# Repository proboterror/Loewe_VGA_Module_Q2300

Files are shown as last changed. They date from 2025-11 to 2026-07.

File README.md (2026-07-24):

# Loewe TVs Q2300 VGA Module
Recreation of VGA module PCB for Loewe TVs with Q2300 chassis.<br>
[Loewe Q2400/Q2500 Chassis VGA Module](https://github.com/proboterror/Loewe_VGA_Module_Q2500)

Project based on schematic from [Loewe Q2300 Chassis Service Manual](doc/loewe_chassis_q2300.pdf)

Schematic and PCB recreated from the scratch in KiCad and verified with Desing/Electrical Rules Checker tools.<br>

Original schematic from [Loewe Q2300 Chassis Service Manual](doc/loewe_chassis_q2300.pdf):
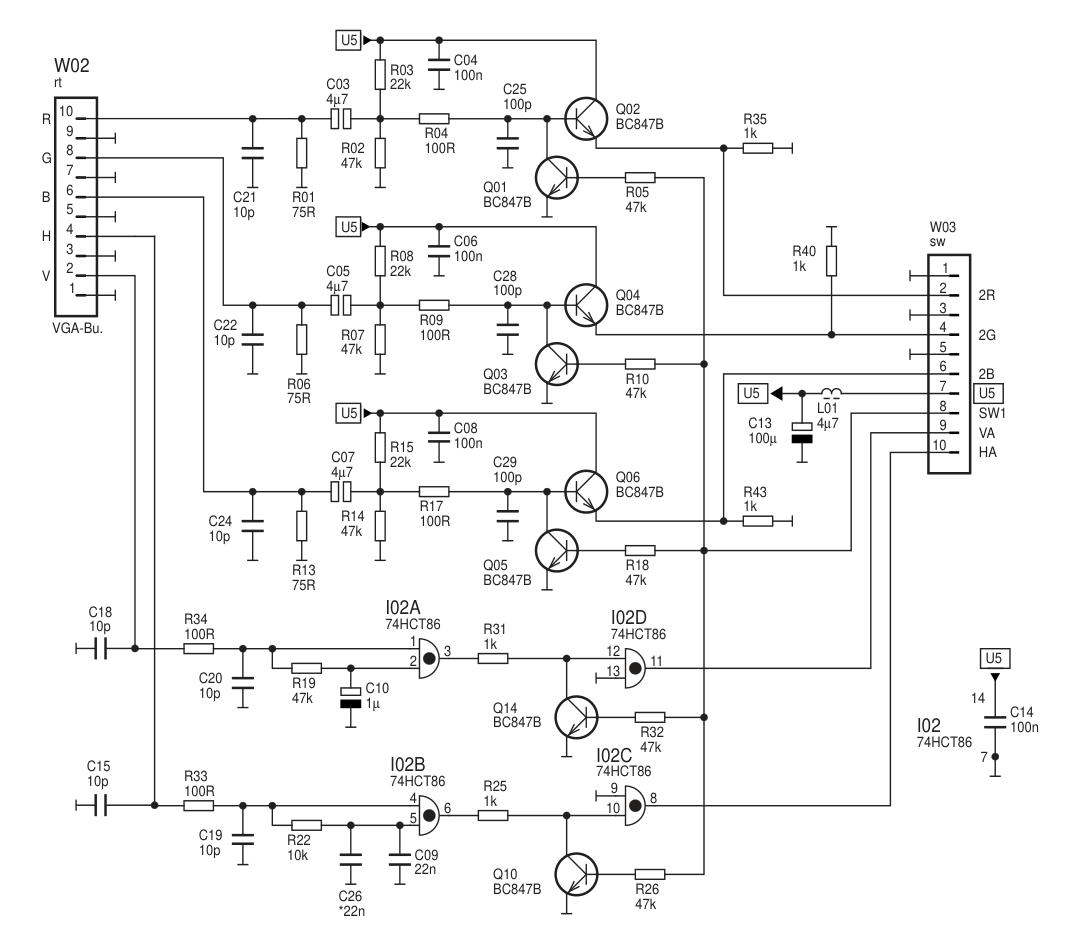
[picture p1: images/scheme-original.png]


Recreated schematic and PCB:
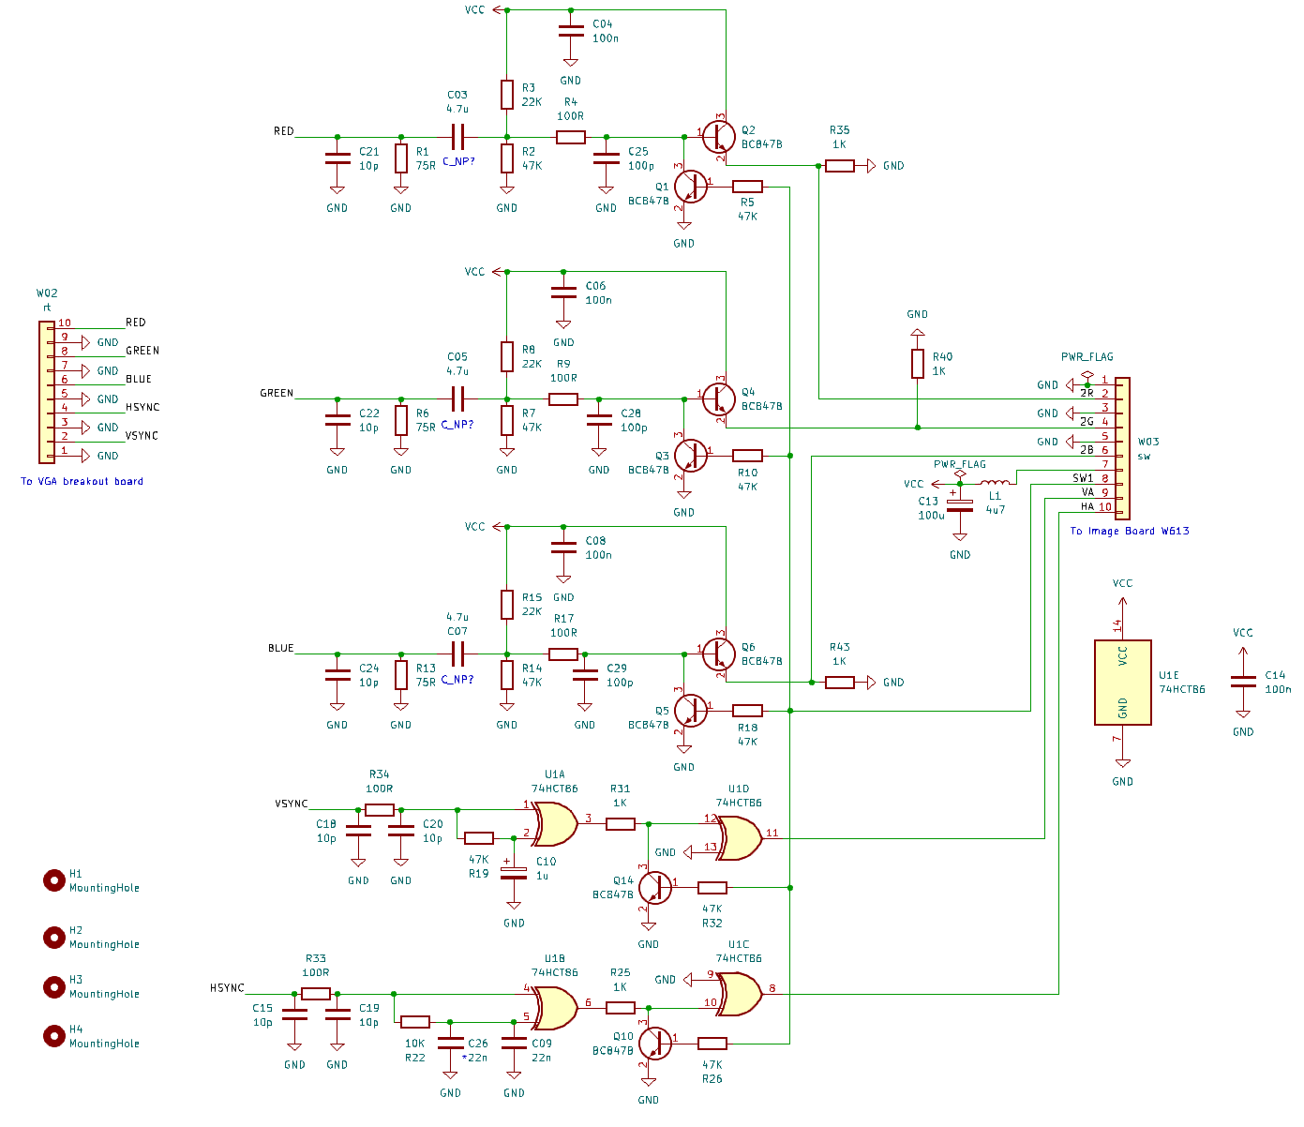
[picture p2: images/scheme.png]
scheme

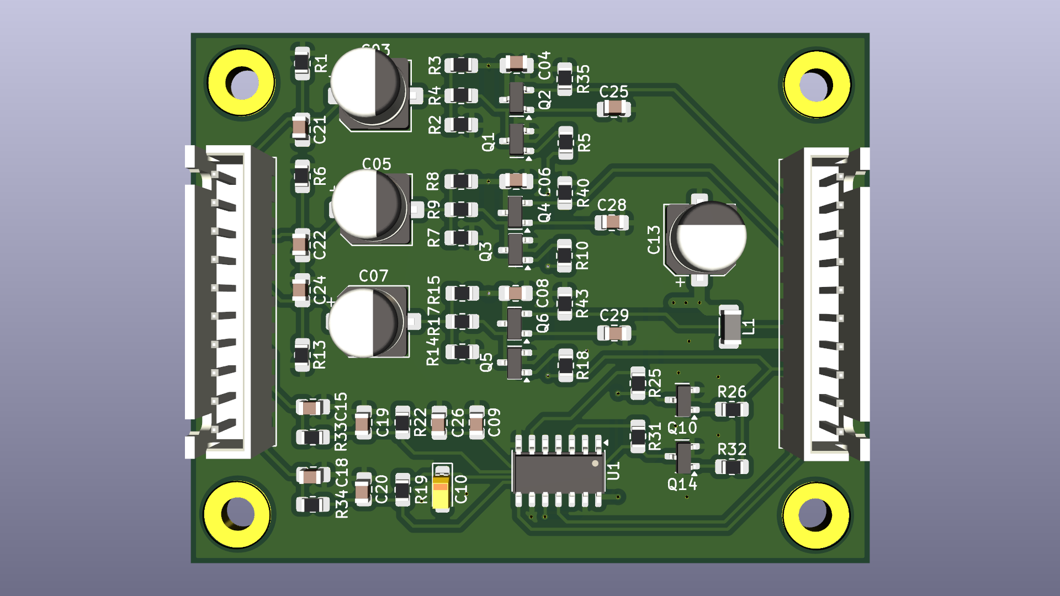
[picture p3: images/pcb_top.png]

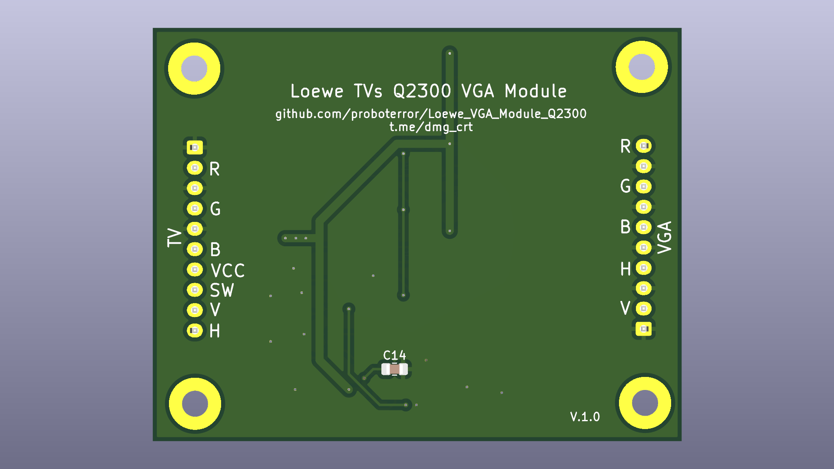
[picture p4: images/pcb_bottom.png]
pcb_bottom

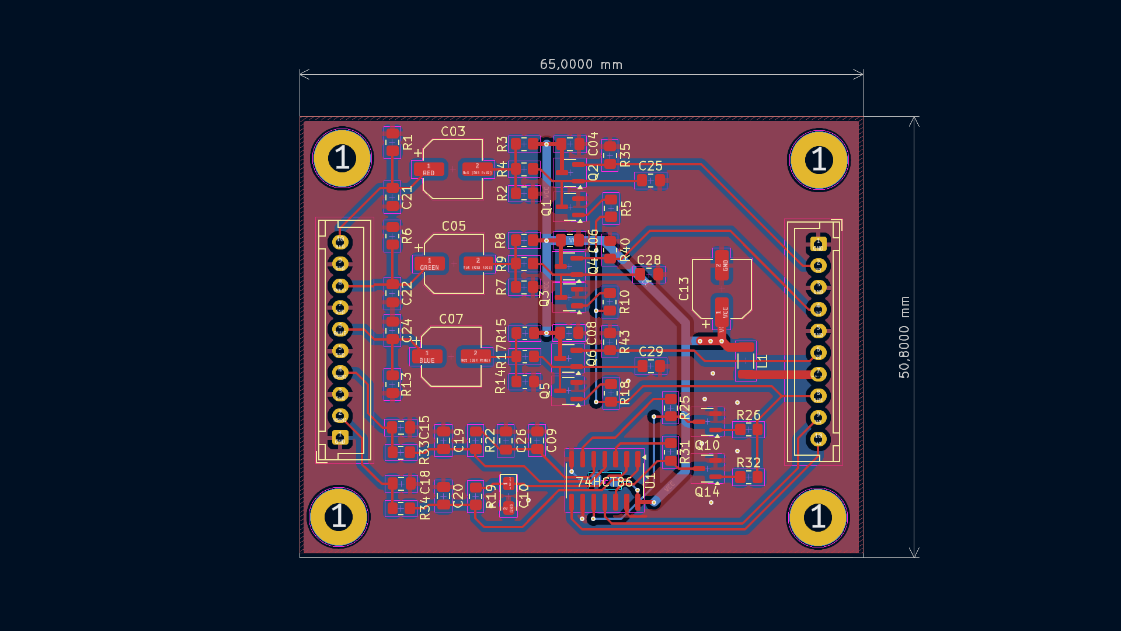
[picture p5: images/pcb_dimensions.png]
pcb_dimensions


VGA connector breakout board:
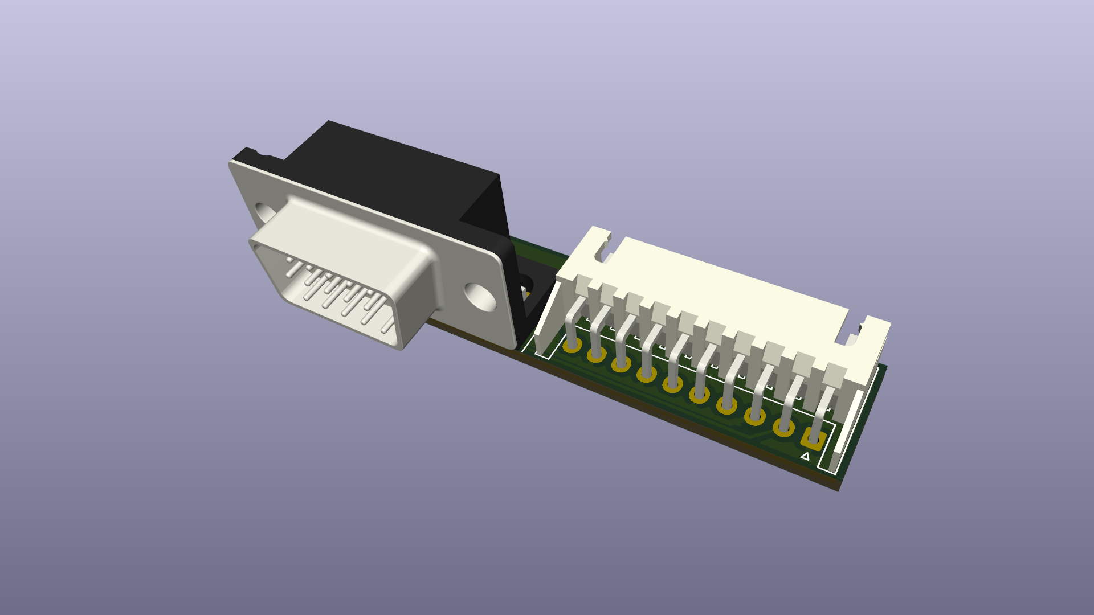
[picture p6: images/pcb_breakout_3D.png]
pcb_breakout_3D

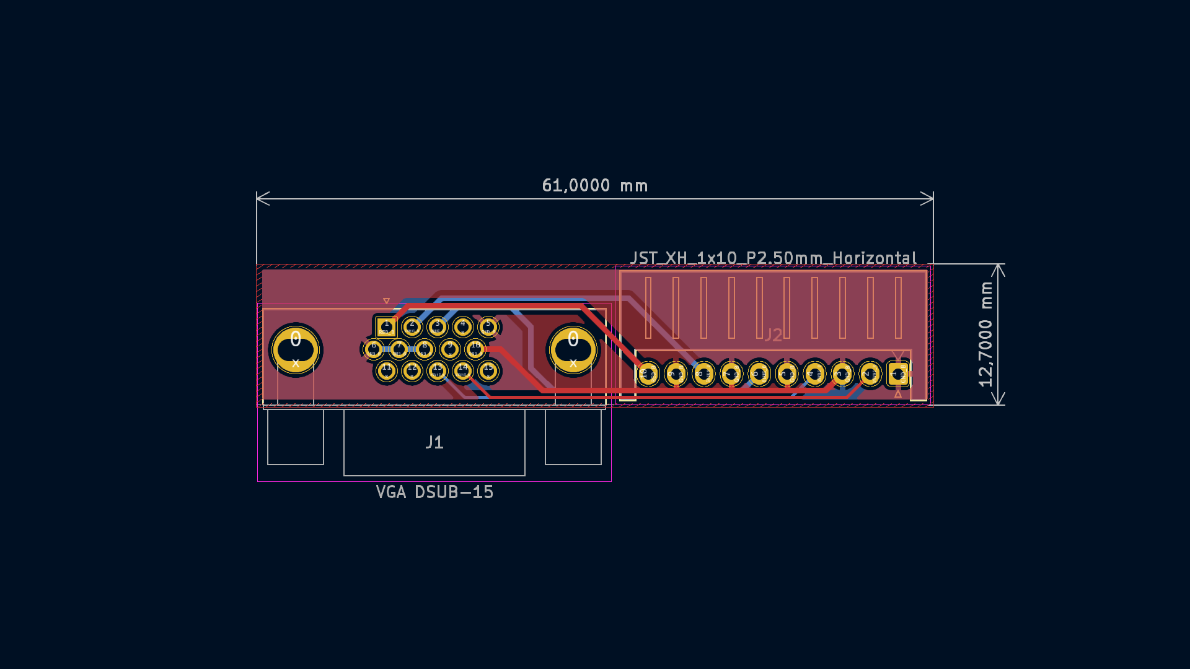
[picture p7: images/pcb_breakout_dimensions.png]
pcb_breakout_dimensions


## Bill of materials
|Reference|Value|Footprint|Qty|
|-----|-----|-----|-----|
|C3,C5,C7|4.7u|Capacitor_SMD:CP_Elec_6.3x5.4|3|
|C4,C6,C8,C14|100n|0805|4|
|C9,C26|22n|0805|2|
|C10|1u|Capacitor_Tantalum_SMD<br>CP_EIA-3216-18_Kemet-A_Pad1.58x1.35mm_HandSolder|1|
|C13|100u|Capacitor_SMD:CP_Elec_6.3x5.7|1|
|C15,C18,C19,C20,C21,C22,C24|10p|0805|7|
|C25,C28,C29|100p|0805|3|
|J1|VGA DSUB-15|DSUB-15-HD_Male_Horizontal_P2.29x1.98mm<br>EdgePinOffset3.03mm_MountingHolesOffset4.94mm|1|
|J2|JST XH 10 pin Horizontal|JST_XH_S10B-XH-A_1x10_P2.50mm_Horizontal|1|
|L1|4u7|Inductor_SMD:1206|1|
|Q1,Q2,Q3,Q4,Q5,Q6,Q10,Q14|BC847B|SOT-23|8|
|R1,R6,R13|75R|0805|3|
|R2,R5,R7,R10,R14,R18,R19,R26,R32|47K|0805|9|
|R3,R8,R15|22K|0805|3|
|R4,R9,R17,R33,R34|100R|0805|5|
|R22|10K|0805|1|
|R25,R31,R35,R40,R43|1K|0805|5|
|U1|74HCT86|SO-14_3.9x8.65mm_P1.27mm|1|
|W2|JST XH 10 pin Vertical|JST_XH_B10B-XH-A_1x10_P2.50mm_Vertical|1|
|W3|JST XH 10 pin Vertical|JST_XH_B10B-XH-A_1x10_P2.50mm_Vertical|1|

+Cables XH 10 pin 20 + 30~50 cm, connectors: same side

## Order boards from manufacturer
Project split to 2 PCBs which should be ordered separately.
Send "gerbers\Breakout Board" and "gerbers\Main Board" folders content packed to separate zip archives.

## Build Notes
L1 inductor can be replaced with 0R resistor or solder bridge.

Pay attention on cables connectors type: same direction or reverse direction.

## Install
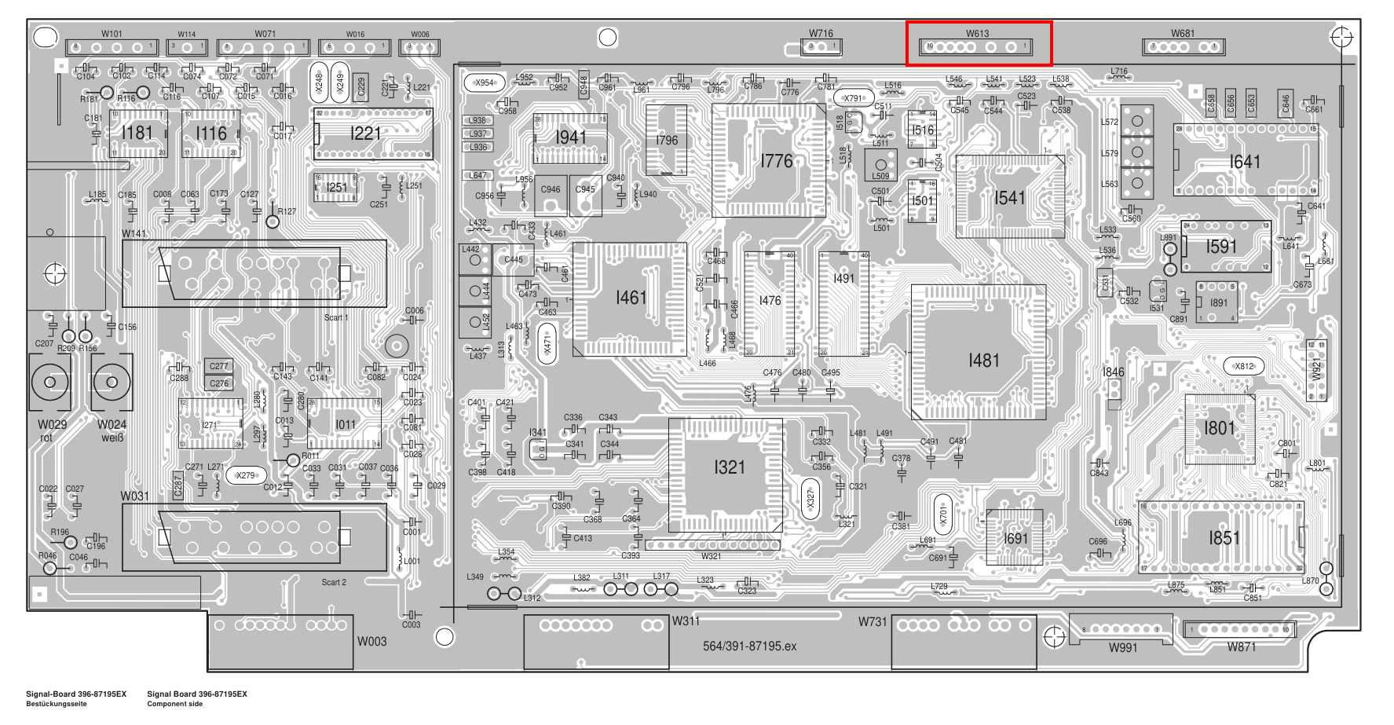
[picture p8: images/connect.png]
Module connection diagram


<https://www.youtube.com/watch?v=7eVl5yn5JIE>:<br>
Select VGA input:<br>
@djcalle1975:
> On the Q23 you have to navigate to channel 196 and if no input is detected within 10 seconds the TV will default back to the last used channel.

VGA Geometry menu:<br>
@peteagas:
> If there is no VGA menu for you on a Q23 after installation and after enabling the option byte setting, press the "i" on the Loewe remote then go to select control level then simple control level set to "No". VGA geometry will now be available to use.

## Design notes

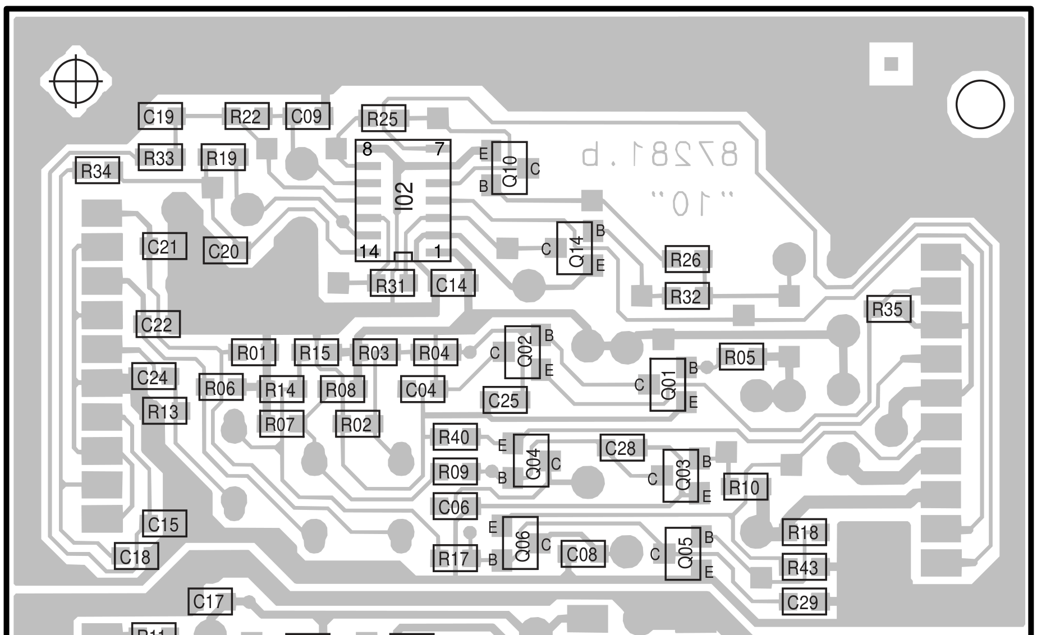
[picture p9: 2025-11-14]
images/pcb.png

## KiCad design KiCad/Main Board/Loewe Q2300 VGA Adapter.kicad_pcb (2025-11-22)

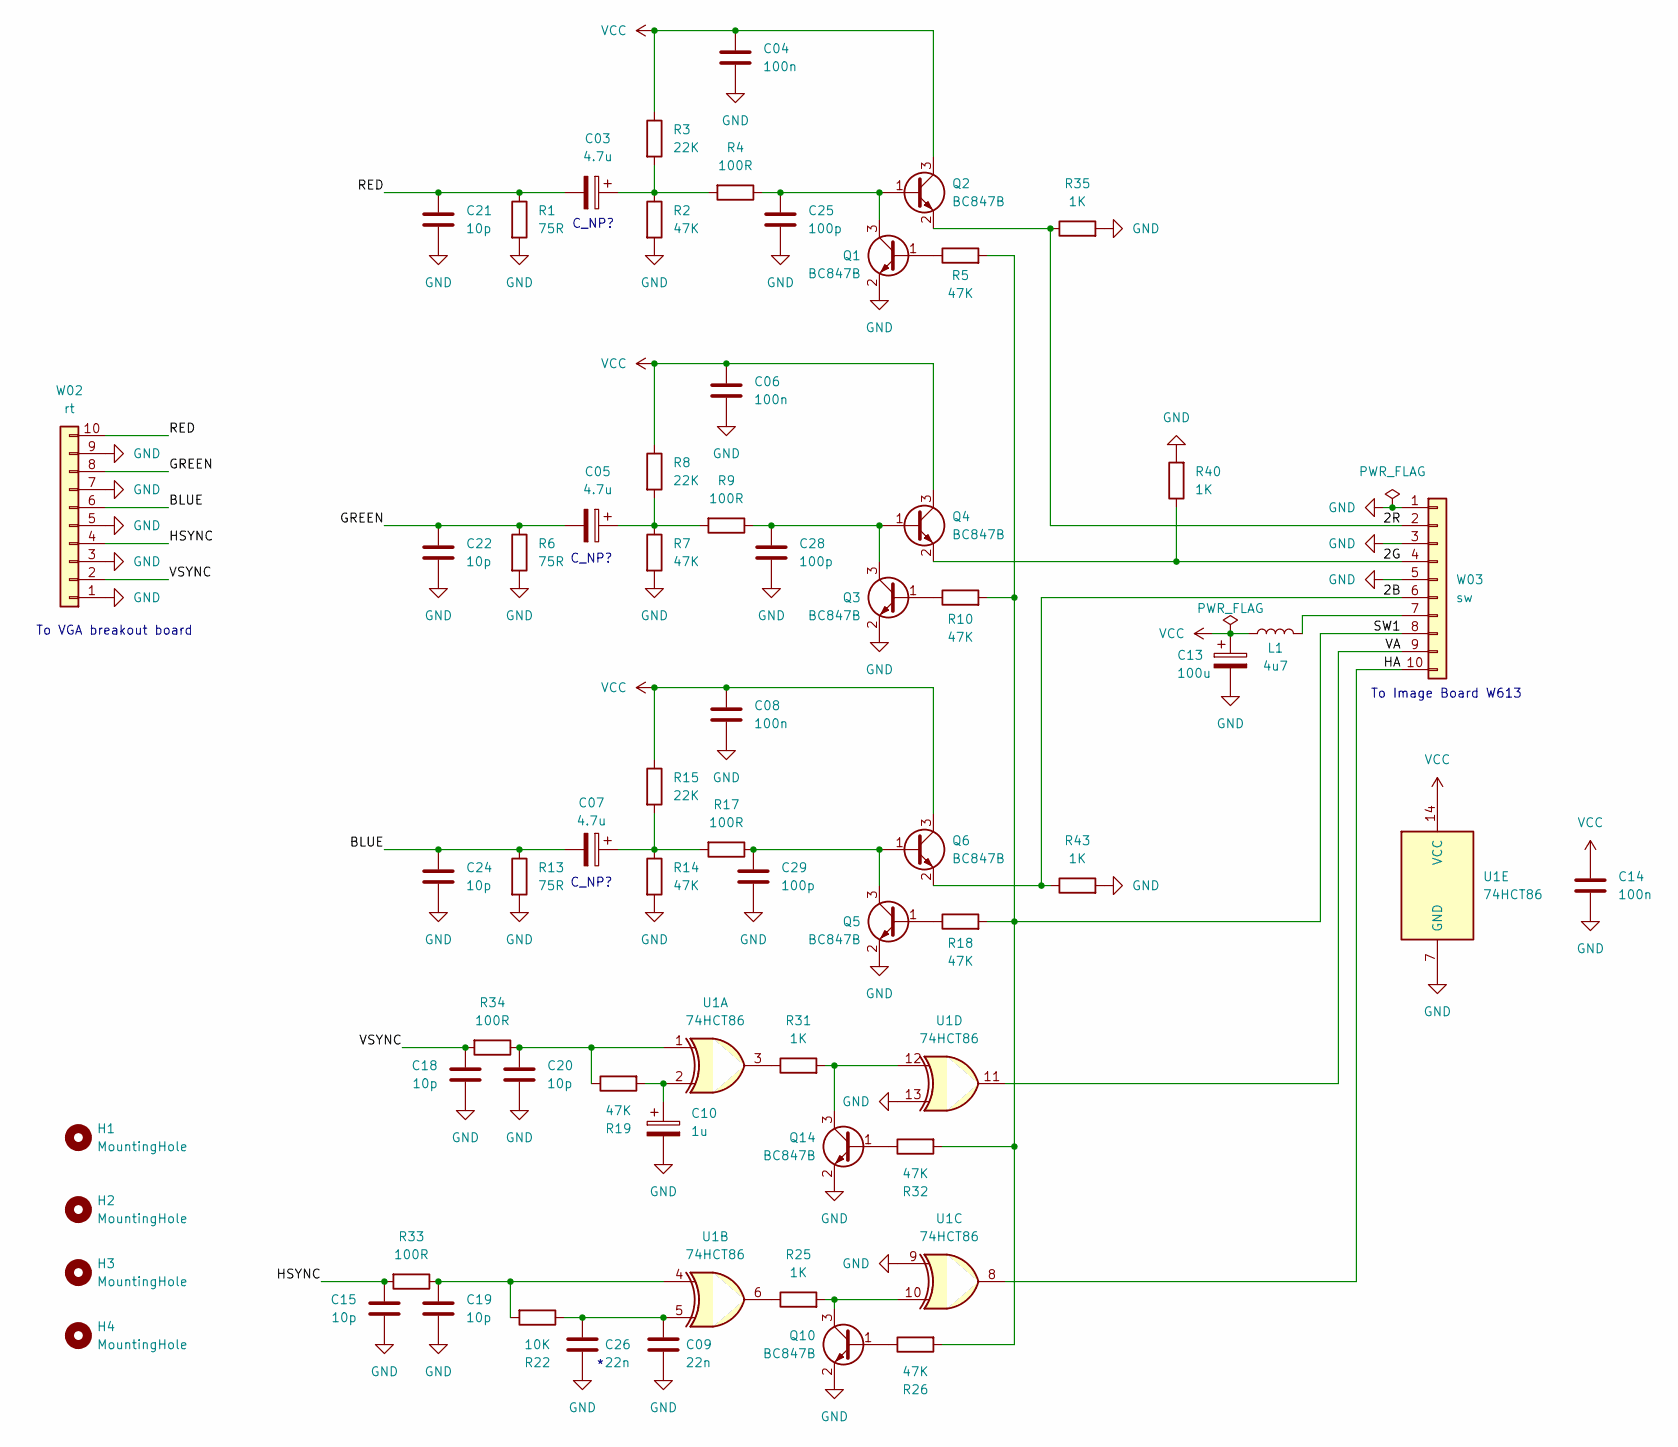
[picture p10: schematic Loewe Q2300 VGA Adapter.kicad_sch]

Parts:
C03, C05, C07: 4.7u; CP_Elec_4x5.4
C04, C06, C08, C14: 100n; C_0805_2012Metric_Pad1.18x1.45mm_HandSolder
C09, C26: 22n; C_0805_2012Metric_Pad1.18x1.45mm_HandSolder
C10: 1u; CP_EIA-3216-18_Kemet-A_Pad1.58x1.35mm_HandSolder
C13: 100u; CP_Elec_6.3x5.7
C15, C18, C19, C20, C21, C22, C24: 10p; C_0805_2012Metric_Pad1.18x1.45mm_HandSolder
C25, C28, C29: 100p; C_0805_2012Metric_Pad1.18x1.45mm_HandSolder
H1, H2, H3, H4: MountingHole; MountingHole_3.2mm_M3_Pad
L1: 4u7; L_1210_3225Metric_Pad1.42x2.65mm_HandSolder
Q1, Q2, Q3, Q4, Q5, Q6, Q10, Q14: BC847B; SOT-23
R1, R6, R13: 75R; R_0805_2012Metric_Pad1.20x1.40mm_HandSolder
R2, R5, R7, R10, R14, R18, R19, R26, R32: 47K; R_0805_2012Metric_Pad1.20x1.40mm_HandSolder
R3, R8, R15: 22K; R_0805_2012Metric_Pad1.20x1.40mm_HandSolder
R4, R9, R17, R33, R34: 100R; R_0805_2012Metric_Pad1.20x1.40mm_HandSolder
R22: 10K; R_0805_2012Metric_Pad1.20x1.40mm_HandSolder
R25, R31, R35, R40, R43: 1K; R_0805_2012Metric_Pad1.20x1.40mm_HandSolder
U1: 74HCT86; SO-14_3.9x8.65mm_P1.27mm
W02: rt; JST_XH_B10B-XH-A_1x10_P2.54mm_Vertical
W03: sw; JST_XH_B10B-XH-A_1x10_P2.54mm_Vertical

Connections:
/2B: Q6.2 (E), R43.1, W03.6
/2G: Q4.2 (E), R40.1, W03.4
/2R: Q2.2 (E), R35.1, W03.2
/BLUE: C07.2, C24.1, R13.1, W02.6
/GREEN: C05.2, C22.1, R6.1, W02.8
/HA: U1.8, W03.10
/HSYNC: C15.2, R33.2, W02.4
/RED: C03.2, C21.1, R1.1, W02.10
/SW1: R5.2, R10.2, R18.2, R26.2, R32.2, W03.8
/VA: U1.11, W03.9
/VSYNC: C18.1, R34.2, W02.2
GND: C04.2, C06.2, C08.2, C09.1, C10.2, C13.2, C14.2, C15.1, C18.2, C19.1, C20.1, C21.2, C22.2, C24.2, C25.2, C26.1, C28.2, C29.2, Q1.2 (E), Q3.2 (E), Q5.2 (E), Q10.2 (E), Q14.2 (E), R1.2, R2.2, R6.2, R7.2, R13.2, R14.2, R35.2, R40.2, R43.2, U1.7 (GND), U1.9, U1.13, W02.1, W02.3, W02.5, W02.7, W02.9, W03.1, W03.3, W03.5
unnamed: C03.1, R2.1, R3.2, R4.2
unnamed: C05.1, R7.1, R8.2, R9.2
unnamed: C07.1, R14.1, R15.2, R17.2
unnamed: C09.2, C26.2, R22.1, U1.5
unnamed: C10.1, R19.2, U1.2
unnamed: C19.2, R22.2, R33.1, U1.4
unnamed: C20.2, R19.1, R34.1, U1.1
unnamed: Q1.1 (B), R5.1
unnamed: C25.1, Q1.3 (C), Q2.1 (B), R4.1
unnamed: Q3.1 (B), R10.1
unnamed: C28.1, Q3.3 (C), Q4.1 (B), R9.1
unnamed: Q5.1 (B), R18.1
unnamed: C29.1, Q5.3 (C), Q6.1 (B), R17.1
unnamed: Q10.1 (B), R26.1
unnamed: Q10.3 (C), R25.2, U1.10
unnamed: Q14.1 (B), R32.1
unnamed: Q14.3 (C), R31.2, U1.12
unnamed: R25.1, U1.6
unnamed: R31.1, U1.3
unnamed: L1.2, W03.7
VCC: C04.1, C06.1, C08.1, C13.1, C14.1, L1.1, Q2.3 (C), Q4.3 (C), Q6.3 (C), R3.1, R8.1, R15.1, U1.14 (VCC)

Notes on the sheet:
To VGA breakout board
C_NP?
To Image Board W613

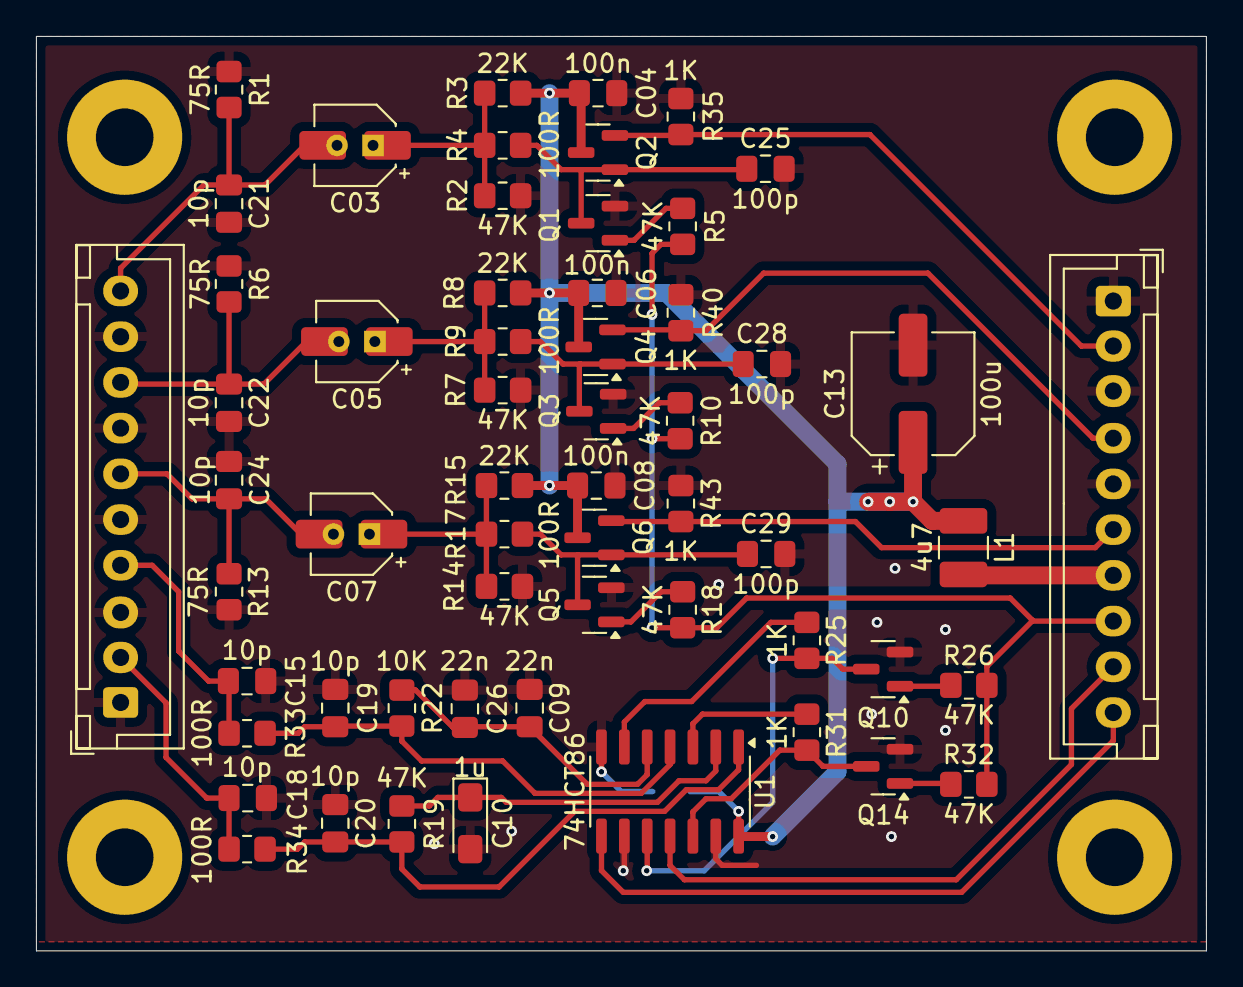
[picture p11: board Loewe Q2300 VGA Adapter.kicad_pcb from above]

Board: 2 copper layers, 65.0 x 50.8 mm, 63 parts (1 on the bottom side), 33 nets.

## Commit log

2025-11-14 Initial schematic and PCB. Project description.
    [Loewe Q2300 Breakout Board.kicad_pcb, Loewe Q2300 Breakout Board.kicad_sch, Loewe Q2300 VGA Adapter.kicad_pcb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]
2025-11-14 Change L1 inductor footprint to 1210 (TDK/EPCOS NLCV32T-4R7M-EF).
    [Loewe Q2300 VGA Adapter.kicad_pcb, Loewe Q2300 VGA Adapter.kicad_sch]
2025-11-14 Change RGB input capacitors footprints to Capacitor_SMD:CP_Elec_4x5.4. Reverse RGB capacitors polarity.
    [Loewe Q2300 VGA Adapter.kicad_pcb, Loewe Q2300 VGA Adapter.kicad_sch]
2025-11-16 Move components values from *.Fab layer to *.SilkS. Align mounting holes positions to 55/40 mm.
    [Loewe Q2300 VGA Adapter.kicad_pcb]
2025-11-22 Add non-standard 2.54 mm JST XH S10B connectors footprints based on KiCad 2.50 mm ones.
2025-11-22 Replace JST XH 2.50 mm with custom 2.54 mm.
    [Loewe Q2300 Breakout Board.kicad_pcb, Loewe Q2300 Breakout Board.kicad_sch, Loewe Q2300 VGA Adapter.kicad_pcb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]
2025-11-22 Edit PCB dimensions drawing.
    [Loewe Q2300 Breakout Board.kicad_pcb]
2025-11-22 Replace footprint for RGB input capacitors with custom combined SMD/THT one.
    [Loewe Q2300 VGA Adapter.kicad_pcb, Loewe Q2300 VGA Adapter.kicad_sch]
2025-11-22 Add version to PCB silkscreen.
    [Loewe Q2300 Breakout Board.kicad_pcb]
2025-11-22 Production V.1.0 gerbers.
    [Loewe Q2300 Breakout Board-B_Cu.gbr, Loewe Q2300 Breakout Board-B_Mask.gbr, Loewe Q2300 Breakout Board-B_Paste.gbr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]
2025-12-14 KiCad projects update paths.
2025-12-14 Replace incorrect Connector_Dsub:DSUB-15-HD_Male with Connector_Dsub:DSUB-15-HD_Female.
    [Loewe Q2300 Breakout Board.kicad_pcb, Loewe Q2300 Breakout Board.kicad_sch]
2025-12-14 Update gerbers.
    [Loewe Q2300 Breakout Board-B_Cu.gbr, Loewe Q2300 Breakout Board-B_Mask.gbr, Loewe Q2300 Breakout Board-B_Paste.gbr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]
